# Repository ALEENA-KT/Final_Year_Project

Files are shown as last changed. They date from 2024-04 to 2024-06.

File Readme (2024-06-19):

#DESIGN AND DEVELOPMENT OF 5KW MODULAR GRID CONNECTED CONVERTER
The primary objective of this project is to develop and implement a state-of-the-art
5KW modular grid-connected converter with the goal of revolutionizing energy conver-
sion systems for increased adaptability and efficiency. In a grid-connected environment,
the converter’s function is to control source power, making it compatible with a range
of load requirements. The converter’s modular design offers a scalable and adaptable
method that enables easy integration into a range of power systems. Because of its
versatility and 5KW capacity, it can be used in both residential and commercial envi-
ronments. The focus on modularity makes it simple to expand or reconfigure to meet
changing energy requirements.
This project report addresses the imperative control objectives of a three-phase
(3Phase) active front end (AFE) converter, aiming to achieve enhanced performance
in line with IEEE standards. The identified control objectives include maintaining a
low value for line current Total Harmonic Distortion (THD) at the AC side (THDi less
than or equal to 5 Percentage), ensuring in-phase operation of AC side voltages and
currents, and achieving superior regulation of the DC link voltage.
In energy processing, pulse width modulation (PWM) techniques are essential for
producing accurate gate signals for power semiconductor devices. This guarantees the
best possible power conversion efficiency and performance. This project pushes the
limits of innovation in energy conversion technology by building upon a wealth of
research in semiconductor devices, converter topologies, PWM techniques, and con-
trollers. With its ability to handle the dynamic challenges of modern power systems
and its contribution to the ongoing evolution of smart grids and renewable energy in-
tegration, the 5KW modular grid-connected converter is a significant milestone in the
search for sustainable and flexible energy solutions

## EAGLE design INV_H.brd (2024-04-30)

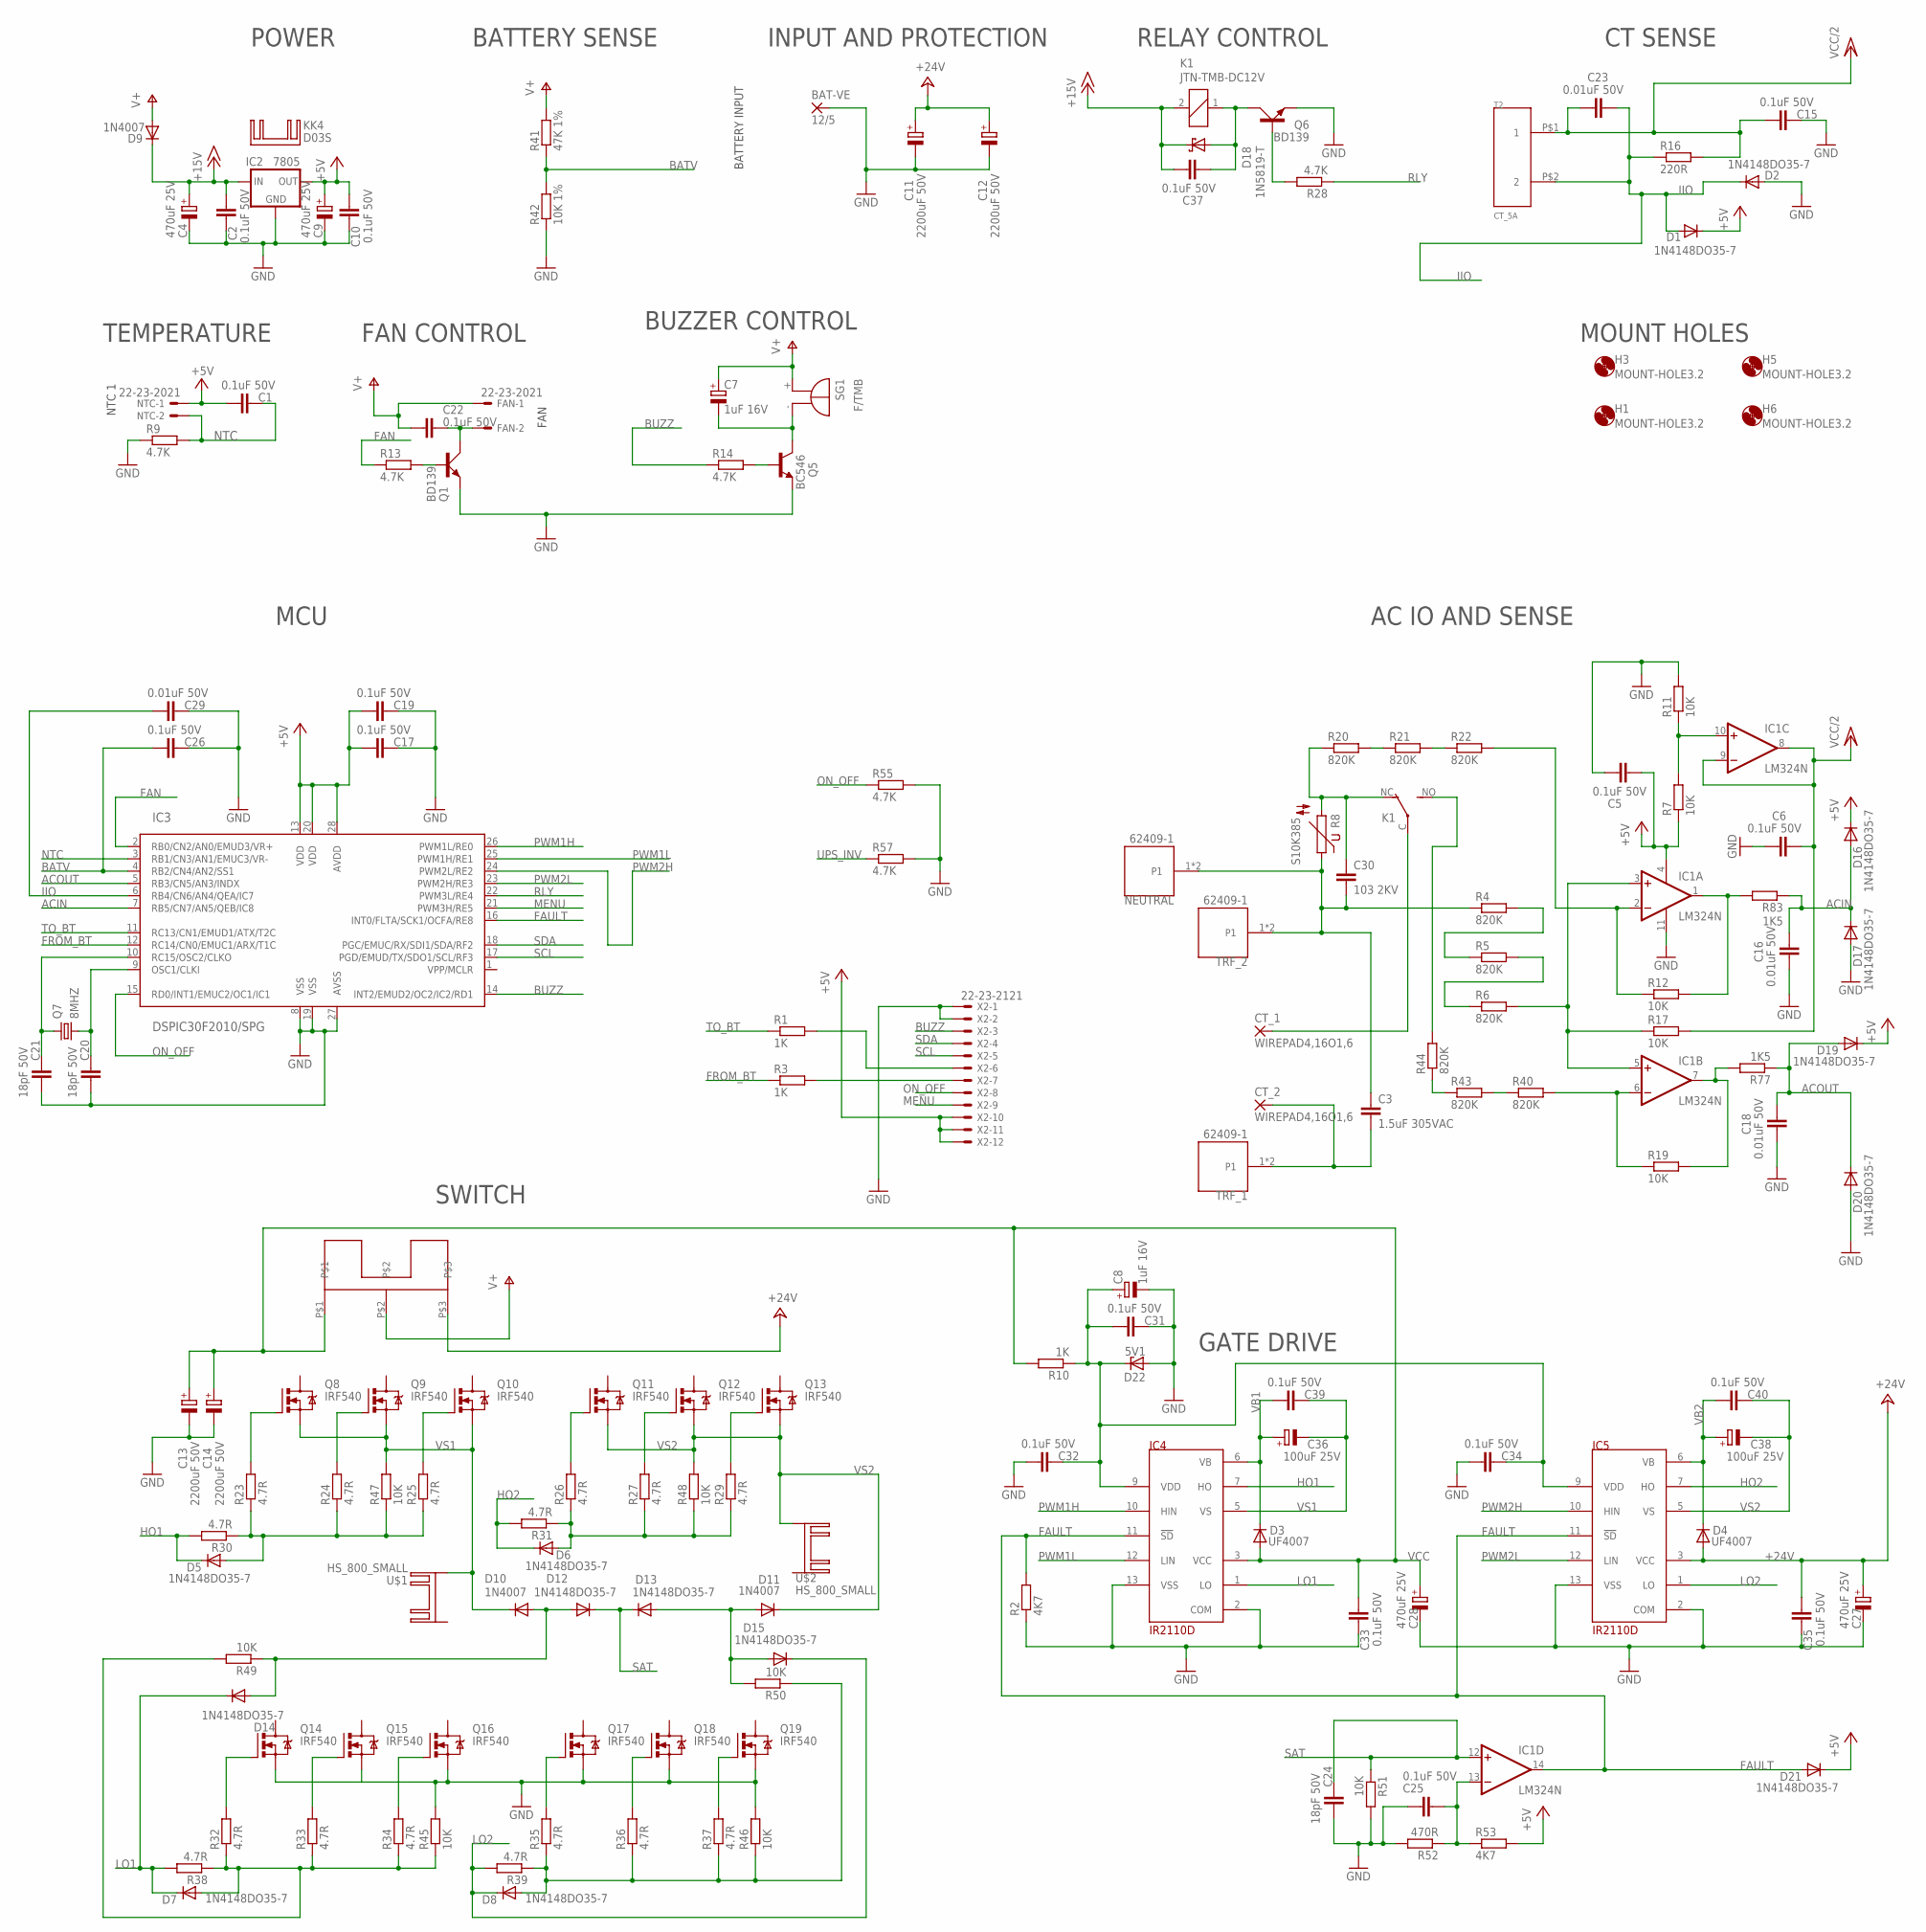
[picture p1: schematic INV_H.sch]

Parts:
BAT-VE: 12/5; 8/5
C1, C2, C5, C6, C10, C15, C17, C19, C22, C25, C26, C31, C32, C33, C34, C35, C37, C39, C40: 0.1uF 50V; C025-025X050
C3: 1.5uF 305VAC; C275-113X316
C4, C9, C27, C28: 470uF 25V; E3,5-8
C7, C8: 1uF 16V; E1,8-4
C11, C12, C13, C14: 2200uF 50V; E7,5-16
C16, C18, C23, C29: 0.01uF 50V; C025-025X050
C20, C21, C24: 18pF 50V; C025-025X050
C30: 103 2KV; C075-032X103
C36, C38: 100uF 25V; E2,5-6
CT_1, CT_2: WIREPAD4,16O1,6; 4,16O1,6
D1, D2, D5, D6, D7, D8, D12, D13, D14, D15, D16, D17, D19, D20, D21: 1N4148DO35-7; DO35-7
D3, D4: UF4007; DO41-10
D9, D10, D11: 1N4007; DO41-10
D18: 1N5819-T; DO41-7.6
D22: 5V1; DO34Z7
FAN: 22-23-2021
H1, H3, H5, H6: MOUNT-HOLE3.2; 3,2
IC1: LM324N; DIL14
IC2: 7805; 78XXS
IC3: DSPIC30F2010/SPG; DIL28-3
IC4, IC5: IR2110D; DIL14
K1: JTN-TMB-DC12V; JT-TMB
KK4: D03S
KK5: HS_800_BIG; 800W_BIG
NEUTRAL: 62409-1; TE_62409-1
NTC: 22-23-2021
Q1, Q6: BD139; TO126AV
Q5: BC546; TO92-EBC
Q7: 8MHZ; HC49/S
Q8, Q9, Q10, Q11, Q12, Q13, Q14, Q15, Q16, Q17, Q18, Q19: IRF540; TO220BV
R1, R3, R10: 1K; 0204/7
R2, R53: 4K7; 0204/7
R4, R5, R6, R20, R21, R22, R40, R43, R44: 820K; 0204/7
R7, R11, R12, R17, R19, R45, R46, R47, R48, R49, R50, R51: 10K; 0204/7
R8: S10K385
R9, R13, R14, R28, R55, R57: 4.7K; 0204/7
R16: 220R; 0204/7
R23, R24, R25, R26, R27, R29, R30, R31, R32, R33, R34, R35, R36, R37, R38, R39: 4.7R; 0204/7
R41: 47K 1%; 0204/7
R42: 10K 1%; 0204/7
R52: 470R; 0204/7
R77, R83: 1K5; 0204/7
SG1: F/TMB
T2: CT_5A
TRF_1, TRF_2: 62409-1; TE_62409-1
U$1, U$2: HS_800_SMALL; 800W_SMALL
X2: 22-23-2121

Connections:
+5V: C1.2, C5.2, C9.+, C10.2, C17.2, C19.2, D1.C, D16.C, D19.C, D21.C, IC1.4 (V+), IC2.OUT, IC3.13 (VDD), IC3.20 (VDD), IC3.28 (AVDD), NTC.1, R7.3 (1), R53.4 (2), X2.10, X2.11, X2.12
+15V: C2.2, C4.+, C37.1, D9.C, D18.C, IC2.IN, K1.2
+24V: C11.+, C12.+, C27.+, C35.2, D4.A, IC5.3 (VCC), KK5.P$3
ACIN: C16.1, D16.A, D17.C, IC3.7 (RB5/CN7/AN5/QEB/IC8), R83.3 (1)
ACOUT: C18.1, D19.A, D20.C, IC3.5 (RB3/CN5/AN3/INDX), R77.3 (1)
BATV: C26.2, IC3.4 (RB2/CN4/AN2/SS1), R41.3 (1), R42.4 (2)
BUZZ: IC3.14 (INT2/EMUD2/OC2/IC2/RD1), R14.3 (1), X2.3
FAN: IC3.2 (RB0/CN2/AN0/EMUD3/VR+), R13.3 (1)
FAULT: D21.A, IC1.14 (OUT), IC3.16 (INT0/FLTA/SCK1/OCFA/RE8), IC4.11 (!SD), IC5.11 (!SD), R2.4 (2)
FROM_BT: IC3.12 (RC14/CN0/EMUC1/ARX/T1C), R3.3 (1)
GND: BAT-VE.P$1, C2.1, C4.-, C5.1, C6.2, C8.-, C9.-, C10.1, C11.-, C12.-, C13.-, C14.-, C15.1, C16.2, C17.1, C18.2, C19.1, C20.2, C21.2, C24.2, C25.2, C26.1, C27.-, C28.-, C29.1, C31.1, C32.2, C33.1, C34.2, C35.1, D2.A, D17.A, D20.A, D22.A, IC1.11 (V-), IC2.GND, IC3.8 (VSS), IC3.19 (VSS), IC3.27 (AVSS), IC4.2 (COM), IC4.13 (VSS), IC5.2 (COM), IC5.13 (VSS), Q1.E, Q5.E, Q6.E, Q14.S, Q15.S, Q16.S, Q17.S, Q18.S, Q19.S, R2.3 (1), R9.3 (1), R11.4 (2), R42.3 (1), R45.4 (2), R46.4 (2), R51.4 (2), R52.4 (2), R55.4 (2), R57.4 (2), X2.1, X2.2
HO1: D5.C, IC4.7 (HO), R30.4 (2)
HO2: D6.C, IC5.7 (HO), R31.4 (2)
IIO: C23.1, C29.2, D1.A, D2.C, IC3.6 (RB4/CN6/AN4/QEA/IC7), R16.3 (1), T2.P$2 (2)
LO1: D7.C, D14.C, IC4.1 (LO), R38.4 (2)
LO2: D8.C, D15.C, IC5.1 (LO), R39.4 (2)
MENU: IC3.21 (PWM3H/RE5), X2.9
unnamed: C3.1, C30.2, NEUTRAL.1, NEUTRAL.2, R4.3 (1), R8.1, TRF_2.1, TRF_2.2
unnamed: R3.4 (2), X2.7
unnamed: C3.2, CT_2.1, TRF_1.1, TRF_1.2
unnamed: CT_1.1, K1.C
unnamed: C30.1, K1.NC (O), R8.2, R20.3 (1)
unnamed: C25.1, IC1.13 (-IN), R52.3 (1), R53.3 (1)
unnamed: IC1.10 (+IN), R7.4 (2), R11.3 (1)
unnamed: R4.4 (2), R5.3 (1)
unnamed: C22.1, FAN.2, Q1.C
unnamed: Q1.B, R13.4 (2)
unnamed: C7.-, Q5.C, SG1.-
unnamed: Q5.B, R14.4 (2)
unnamed: R5.4 (2), R6.3 (1)
unnamed: C20.1, IC3.9 (OSC1/CLKI), Q7.2
unnamed: IC1.3 (+IN), IC1.5 (+IN), R6.4 (2), R17.3 (1)
unnamed: C21.1, IC3.10 (RC15/OSC2/CLKO), Q7.1
unnamed: IC1.2 (-IN), R12.3 (1), R22.4 (2)
unnamed: D10.A, D12.A, D14.A, R49.3 (1)
unnamed: IC1.6 (-IN), R19.3 (1), R40.4 (2)
unnamed: R20.4 (2), R21.3 (1)
unnamed: R21.4 (2), R22.3 (1)
unnamed: K1.NO (S), R44.4 (2)
unnamed: R43.3 (1), R44.3 (1)
unnamed: Q8.G, R23.4 (2)
unnamed: Q9.G, R24.4 (2)
unnamed: Q10.G, R25.4 (2)
unnamed: D5.A, R23.3 (1), R24.3 (1), R25.3 (1), R30.3 (1), R47.3 (1)
unnamed: R40.3 (1), R43.4 (2)
unnamed: D7.A, R32.3 (1), R33.3 (1), R34.3 (1), R38.3 (1), R45.3 (1), R49.4 (2)
unnamed: Q14.G, R32.4 (2)
unnamed: Q15.G, R33.4 (2)
unnamed: Q16.G, R34.4 (2)
unnamed: Q11.G, R26.4 (2)
unnamed: D6.A, R26.3 (1), R27.3 (1), R29.3 (1), R31.3 (1), R48.3 (1)
unnamed: D8.A, R35.3 (1), R36.3 (1), R37.3 (1), R39.3 (1), R46.3 (1), R50.3 (1)
unnamed: C37.2, D18.A, K1.1, Q6.C
unnamed: Q17.G, R35.4 (2)
unnamed: Q6.B, R28.4 (2)
unnamed: Q18.G, R36.4 (2)
unnamed: Q19.G, R37.4 (2)
unnamed: Q13.G, R29.4 (2)
unnamed: Q12.G, R27.4 (2)
unnamed: D11.A, D13.A, D15.A, R50.4 (2)
unnamed: R1.4 (2), X2.6
unnamed: IC1.7 (OUT), R19.4 (2), R77.4 (2)
unnamed: IC1.1 (OUT), R12.4 (2), R83.4 (2)
NTC: C1.1, IC3.3 (RB1/CN3/AN1/EMUC3/VR-), NTC.2, R9.4 (2)
ON_OFF: IC3.15 (RD0/INT1/EMUC2/OC1/IC1), R55.3 (1), X2.8
PWM1H: IC3.26 (PWM1L/RE0), IC4.10 (HIN)
PWM1L: IC3.25 (PWM1H/RE1), IC4.12 (LIN)
PWM2H: IC3.24 (PWM2L/RE2), IC5.10 (HIN)
PWM2L: IC3.23 (PWM2H/RE3), IC5.12 (LIN)
RLY: IC3.22 (PWM3L/RE4), R28.3 (1)
SAT: C24.1, D12.C, D13.C, IC1.12 (+IN), R51.3 (1)
SCL: IC3.17 (PGD/EMUD/TX/SDO1/SCL/RF3), X2.5
SDA: IC3.18 (PGC/EMUC/RX/SDI1/SDA/RF2), X2.4
TO_BT: IC3.11 (RC13/CN1/EMUD1/ATX/T2C), R1.3 (1)
UPS_INV: R57.3 (1)
V+: C7.+, C22.2, D9.A, FAN.1, KK5.P$2, R41.4 (2), SG1.+
VB1: C36.+, C39.2, D3.C, IC4.6 (VB)
VB2: C38.+, C40.2, D4.C, IC5.6 (VB)
VCC: C13.+, C14.+, C28.+, C33.2, D3.A, IC4.3 (VCC), KK5.P$1, R10.4 (2)
VCC/2: C6.1, C15.2, C23.2, IC1.8 (OUT), IC1.9 (-IN), R16.4 (2), R17.4 (2), T2.P$1 (1)
VDD: C8.+, C31.2, C32.1, C34.1, D22.C, IC4.9 (VDD), IC5.9 (VDD), R10.3 (1)
VS1: C36.-, C39.1, D10.C, IC4.5 (VS), Q8.S, Q9.S, Q10.S, R47.4 (2), U$1.P$2
VS2: C38.-, C40.1, D11.C, IC5.5 (VS), Q11.S, Q12.S, Q13.S, R48.4 (2), U$2.P$1

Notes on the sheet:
POWER
INPUT AND PROTECTION
BATTERY INPUT
NTC 1
FAN
AC IO AND SENSE
GATE DRIVE
MCU
SWITCH
MOUNT HOLES
BATTERY SENSE
TEMPERATURE
FAN CONTROL
BUZZER CONTROL
RELAY CONTROL
CT SENSE

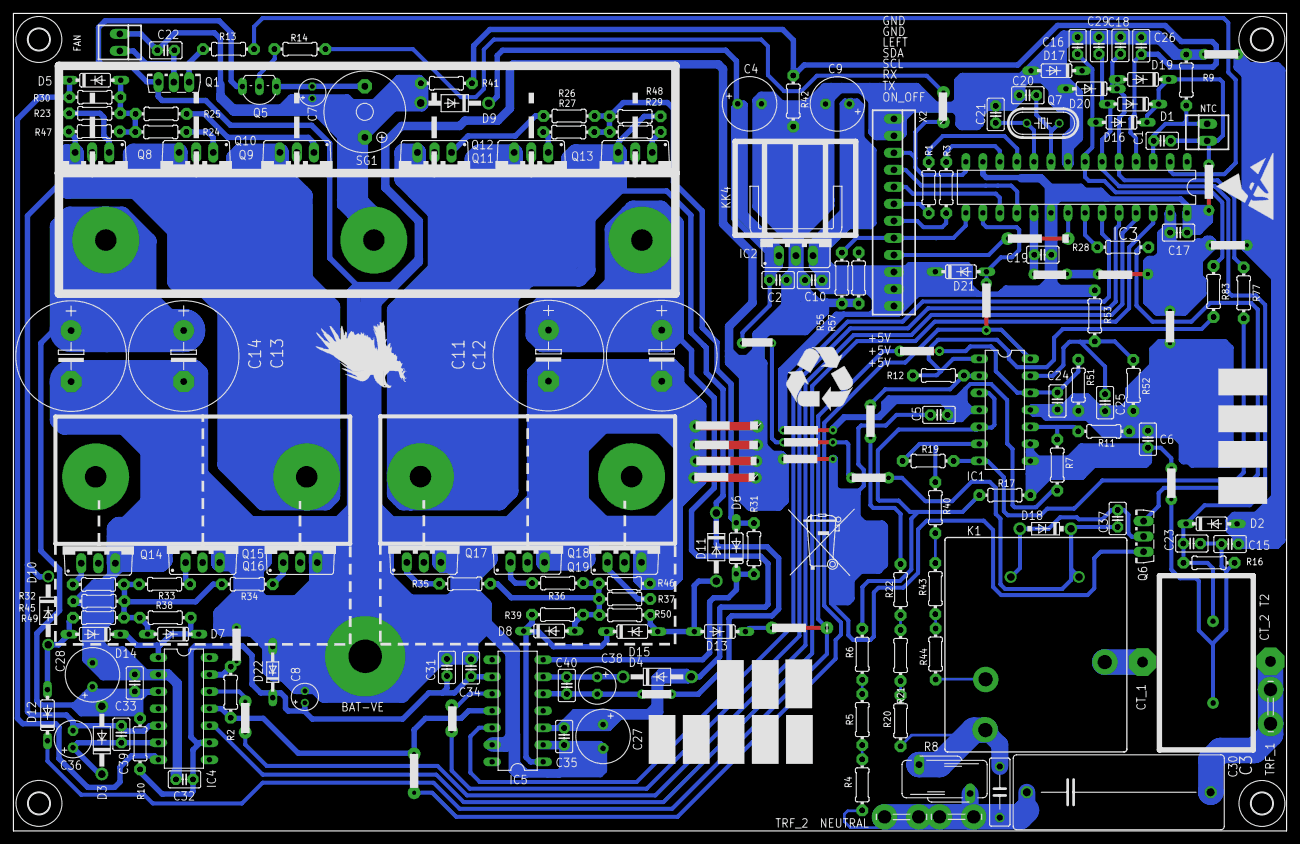
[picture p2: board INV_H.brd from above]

Board: 2 copper layers, 190.0 x 122.0 mm, 162 parts (0 on the bottom side), 82 nets.

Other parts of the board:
U$3: ESD_10.00
U$4: MUELLTONNE_10.00
U$5: RECYCLING_10.00
U$6: EAGLE-PLC-10MM
